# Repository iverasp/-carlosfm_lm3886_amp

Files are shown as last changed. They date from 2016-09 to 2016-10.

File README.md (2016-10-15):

## LM3886 amplifier

This PCB is for an LM3886 amplifier, based on schematics by Carlos.  
Pin 11 is removed to allow routing.

### Dimensions of parts

100nF caps: 15mm spacing, 18x5.5mm L x W  
2200uF caps: 7.5mm spacing, 18mm diameter  
3.3nF caps: 7.5mm spacing, 10x3mm L x W  
3.3uF caps: 22.5mm spacing, 26.5x11mm L x W  
330pF cap: 5mm spacing, 7.5x4mm L x W  

1W resistors: L=10mm (raised above PCB to provide cooling)  
other resistors: L=10mm

### Remaining parts

Feedback resistor (2k) is placed on chip terminals (3, 9)  
Resistor RM (10k) is placed on chip terminals (8, 4)  
Short the pads A1 and A2 using a wire  
The 2.2uF input cap is too big to fit on the board. Place it and the 15k resistor somewhere convenient instead (e.g. on the RCA connector)  
The Zobel network is placed on the speaker terminals

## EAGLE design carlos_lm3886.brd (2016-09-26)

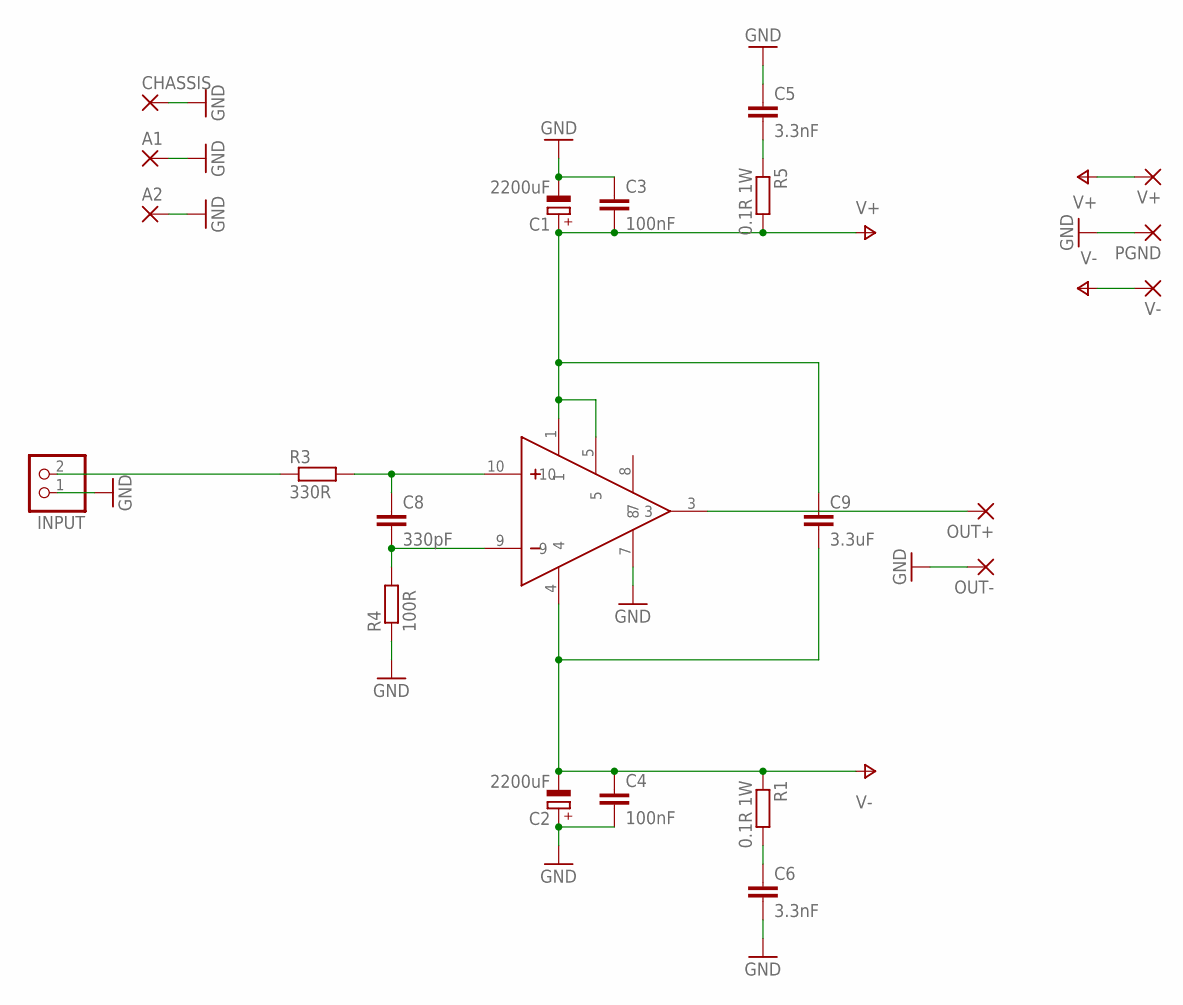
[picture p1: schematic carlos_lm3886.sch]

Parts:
A1, A2: 2,54/1,0
C1, C2: 2200uF; E7,5-18
C3, C4: 100nF; C150-054X183
C5, C6: 3.3nF; C075-032X103
C8: 330pF; C050-045X075
C9: 3.3uF; C225-087X268
CHASSIS: 2,54/1,0
INPUT: PINHD-1X2; 1X02
OUT+: 2,54/1,0
OUT-: 2,54/1,0
PGND: 2,54/1,0
R1, R5: 0.1R 1W; 0309/10
R3: 330R; 0207/10
R4: 100R; 0207/10
U$1: LM3886T; TO220-11
V+: 2,54/1,0
V-: 2,54/1,0

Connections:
GND: A1.1, A2.1, C1.-, C2.+, C3.1, C4.2, C5.1, C6.2, CHASSIS.1, INPUT.1, OUT-.1, PGND.1, R4.1, U$1.7
unnamed: INPUT.2, R3.1
unnamed: C6.1, R1.2
unnamed: C5.2, R5.1
unnamed: C8.1, R3.2, U$1.10
unnamed: C8.2, R4.2, U$1.9
unnamed: OUT+.1, U$1.3
V+: C1.+, C3.2, C9.1, R5.2, U$1.1, U$1.5, V+.1
V-: C2.-, C4.1, C9.2, R1.1, U$1.4, V-.1

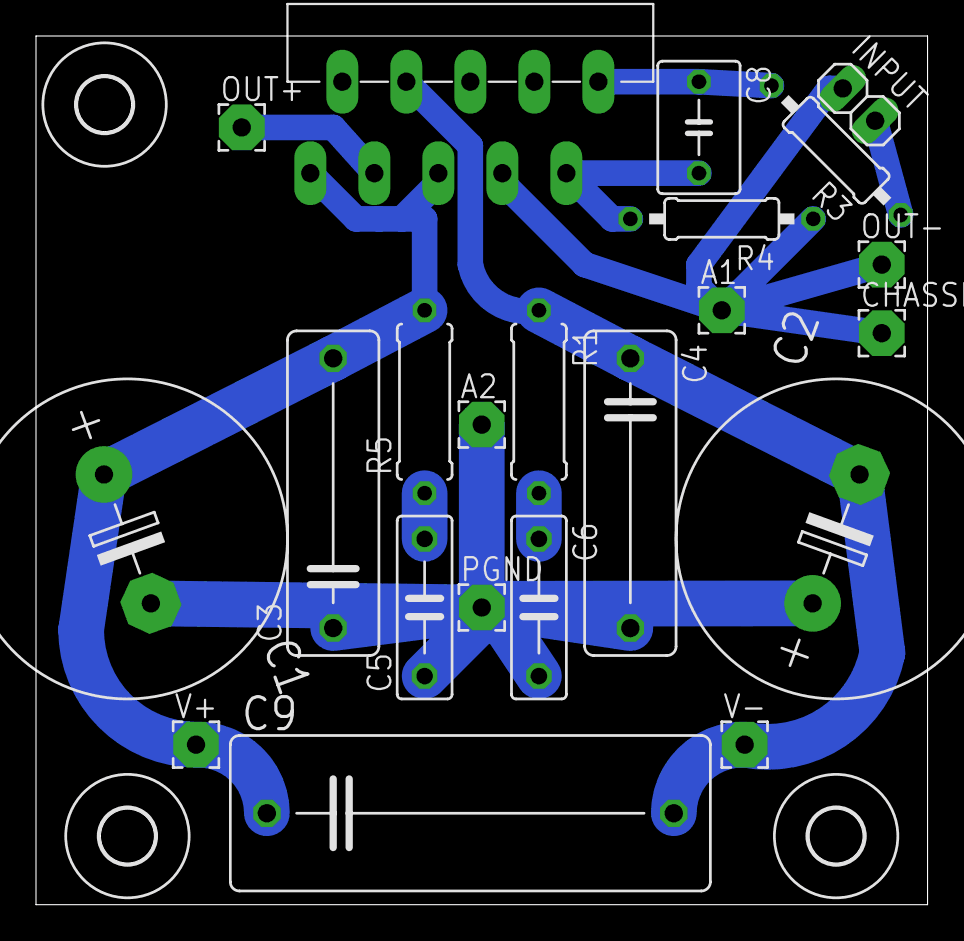
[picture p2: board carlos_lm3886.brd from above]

Board: 2 copper layers, 49.5 x 48.3 mm, 25 parts (0 on the bottom side), 9 nets.

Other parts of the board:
U$2, U$3, U$4: 3,0

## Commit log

2016-09-24 schematic completed
    [carlos_lm3886.brd, carlos_lm3886.sch]
2016-09-24 layout without traces completed
    [carlos_lm3886.brd, carlos_lm3886.sch]
